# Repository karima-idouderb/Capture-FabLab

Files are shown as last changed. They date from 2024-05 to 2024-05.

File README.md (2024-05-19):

# Capture FabLab Project

## Authors
- [BELABDELLI Rizlène](https://github.com/Riizlene)
- [BOUGHERARA Hanane](https://github.com/hanane-bougherara)
- [IDOUDERB Karima](https://github.com/karima-idouderb)
- [OUERFILI Chaïma](https://github.com/Chaimaaaaaaaaaaa)

## Overview
The Capture FabLab project was designed to address a crucial need within the FabLab: project documentation. Often overlooked or considered tedious by users, the documentation process has been simplified through a system that captures videos of the work being done and automatically uploads them to a dedicated server. This project aims to make documentation more accessible and attractive, encouraging comprehensive and regular recording throughout a project's lifecycle. This will facilitate the continuation, improvement, reproduction, and collaboration on projects within the FabLab community.

## Table of Contents
1. [Introduction](#introduction)
2. [Client Requirements](#client-requirements)
3. [System Architecture](#system-architecture)
4. [Project Development Stages](#project-development-stages)
5. [Project Validation](#project-validation)
6. [Conclusion](#conclusion)

## Introduction
The Capture FabLab project was initiated to meet a critical need in the FabLab: project documentation. Users often neglect or find this step tedious. To streamline this process, we developed a system that captures videos of ongoing work and automatically sends them to a dedicated server. The primary goal is to make documentation more accessible and appealing, thereby encouraging users to document their projects comprehensively and consistently throughout their development. This initiative aims to facilitate the continuation, improvement, reproduction, and collaboration on projects within the FabLab.

## Client Requirements
- **Video Recording Control**: Ability to start and stop video recording on demand.
- **User-friendly Interface**: Simple interface with easily identifiable buttons for starting and stopping video recording, ensuring intuitive use.
- **Battery Power**: The system must be powered by a rechargeable battery with a minimum autonomy of 6 hours and a maximum recharge time of 8 hours.
- **Recording Indicator**: An LED should clearly indicate when video recording is in progress.
- **Framerate Adjustment**: A dial to adjust the video framerate, providing flexibility in recording quality.
- **Video Storage on Dedicated Server**: Set up a server to store captured videos, ensuring data preservation and availability for FabLab users.
- **Automatic Data Transfer**: Videos should be automatically transferred from the Raspberry Pi 4 (or other components) to the server upon recording, ensuring continuous documentation.
- **Ease of Assembly for Makers**: The system should be easy to assemble and reproduce, encouraging wider adoption within the FabLab community.
- **Portable and Practical Prototype**: The prototype should be compact and lightweight for easy relocation and use in different FabLab contexts.

## System Architecture
- **Raspberry Pi 4**: Acts as the system's brain, running Python code to control video capture, manage webcam settings, handle recording, and manage video transfers to the server.
- **Webcam**: Used to capture videos of FabLab projects, connected to the Raspberry Pi 4 and controlled by the Python code.
- **External Battery**: Provides continuous power for a minimum of 6 hours as required by the client.
- **PCB (Printed Circuit Board)**: Connects and organizes electronic components, ensuring a compact layout and stable connections.
- **Enclosure**: A specially designed box houses and protects all system components, robust enough for FabLab environments while being compact for easy transport.

## Project Development Stages
1. **Research and Integration of Video Recording Code**: We began by researching and testing Python codes to capture videos from a webcam and store them on the Raspberry Pi 4. Once a functional code was found, it was modified to integrate into the system, ensuring basic recording functionality.
2. **Integration of Control Buttons**: Physical buttons were added to the system to start and stop video recording. These buttons were connected to the Raspberry Pi 4 and programmed to trigger the appropriate actions in the Python code.
3. **Framerate Selection Using a Strip Switch**: A strip switch was used to allow users to select different predefined framerate values for the video, as the Raspberry Pi 4 can only handle numerical values for framerate. This approach was chosen over a potentiometer to avoid additional analog-to-digital conversion.
4. **Testing and Adjustments**: After integrating the main functionalities, tests were conducted to ensure everything worked correctly. Adjustments were made to the code and hardware based on test results to ensure system reliability.
5. **Enclosure Design**: During development, the enclosure design was finalized to house all components neatly.

## Project Validation
- **Regular Client Meetings**: Bi-weekly meetings with the client were held to discuss project progress, gather feedback on developed features, and obtain advice and recommendations. These meetings ensured transparent and effective communication, ensuring the project met the client's needs.
- **Regular Testing**: Continuous testing was performed throughout development to verify that all system functionalities worked correctly, including video recording, control buttons, framerate selection, etc.
- **Internal Team Meetings**: Regular team meetings were held to organize tasks, discuss challenges, and resolve any obstacles. These meetings ensured effective collaboration and smooth project progress.

## Conclusion
The Capture FabLab project has been successful on many fronts. Not only did we deliver a functional and reliable prototype on time, but we also gained valuable skills and experiences for future projects. Despite the challenges encountered, our determination and commitment were key to our success. This project represents an important milestone in our professional journey, and we are proud of the contribution we have made to the FabLab community.

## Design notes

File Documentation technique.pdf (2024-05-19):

BELABDELLI Rizlène
BOUGHERARA Hanane
IDOUDERB Karima
OUERFILI Chaïma

# Documentation Technique: Système d'Enregistrement Vidéo avec Raspberry Pi

## Sommaire

## Introduction

Ce document fournit des instructions détaillées pour la réalisation d'un système d'enregistrement vidéo à l'aide d'un Raspberry Pi. Le projet nécessite un ensemble spécifique de matériel ainsi que des étapes d'installation logicielle et de configuration.
Vous trouverez sur le lien github suivant le code nécessaire à la réalisation de ce projet ainsi que le fichier pour réaliser le PCB.
https://github.com/karima-idouderb/Capture-FabLab.git

## Matériel Requis

- Raspberry Pi 4
- Micro SD et Adaptateur
- Webcam USB
- 2 LEDs
- 2 Boutons
- Strip switch EECO
- PCB
- Jumpers femelle femelle
- Écran, clavier, souris et câble HDMI (+adaptateur Micro HDMI-HDMI) pour le coder sur la carte

## Étapes de Configuration

### 1. Installation du Système d'Exploitation sur la Carte SD

Utilisez Raspberry Pi Imager pour cette étape.

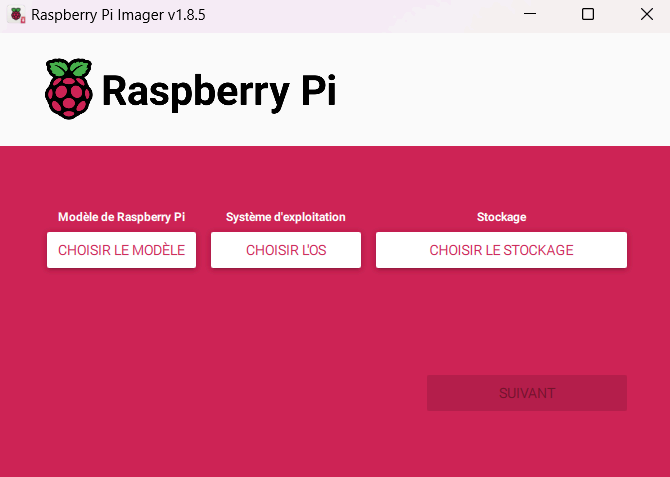
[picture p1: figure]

### 2. Démarrage du Raspberry Pi

Suivez simplement les instructions du programme de configuration initiale. Dans notre exemple, nous avons utilisé "abc" comme nom d'utilisateur et mot de passe. Assurez-vous de modifier le chemin d'enregistrement des vidéos si vous utilisez un nom d'utilisateur différent.

result = cv2.VideoWriter('/home/’NOM_UTILISATEUR’/Projet/Videos/' + nom_fichier + '.avi', cv2.VideoWriter_fourcc(*'MJPG'), fps, size)

### 3. Installation des Librairies Nécessaires

Utilisez les commandes suivantes pour installer les librairies requises:

- OpenCV (pour l'enregistrement vidéo à partir de la caméra):

sudo apt install python3-opencv

- LGPIO (pour gérer les GPIO de la Raspberry Pi):

sudo apt install python3-rpi-lgpio

### 4. Code pour l'Enregistrement Vidéo

Ajoutez le fichier "final.py" dans le répertoire suivant (créez-le si nécessaire):

/home/abc/Projet

Les vidéos seront enregistrées dans le répertoire suivant:

/home/abc/Projet/Videos

Pour lancer le programme au démarrage, ajoutez une ligne dans le fichier "rc.local". Utilisez la commande suivante pour modifier le fichier:

sudo nano /etc/rc.local

Ajoutez la ligne suivante avant "exit 0":

sudo python3 /home/abc/Projet/final.py &

Quelques commentaires sur le code :
La variable fps à la ligne 62 ne représente pas exactement le nombre de frames par seconde. Il y a un petit décalage probablement dû à l'exécution de la boucle. Cependant, la modification de cette valeur permet d'ajuster la vitesse de l'enregistrement. Une valeur de 5 sur la molette correspond à peu près à la vitesse réelle, 1 étant plus lent et 9 plus rapide.

### 5. Configuration du Serveur

Avec l'aide de monsieur Julien Vincent, nous avons mis en place un serveur web Apache accessible à l'adresse suivante : http://pc5033.polytech.upmc.fr/~pltuser/. Ce serveur est uniquement accessible depuis l'intérieur du réseau Polytech.
Afin de faciliter l'envoi de données sans avoir à entrer un mot de passe, nous avons généré une clé privée sur la Raspberry Pi 4. Cette clé est enregistrée du côté du serveur à l'aide de la commande suivante :

ssh-keygen -t n° de la clé publique (.pub) du serveur.

Pour comparer le contenu à envoyer avec ce qui est déjà présent sur le serveur, nous utilisons la commande rsync :
rsync -arv /home/abc/Projet/Videos/ pltuser@pc5033.polytech.upmc.fr:/home/pltuser/Videos Autrement dit, cela nous permettra de synchroniser les données.

Pour automatiser les commandes, nous avons édité le fichier crontab. Nous nous sommes aidés de Crontab Generator pour cette étape.

Pour supprimer toutes les deux semaines les vidéos de plus de 5 jours, nous avons ajouté la commande suivante au crontab :
0 0 */14 * * find /home/Projet/Videos/ -name '*.avi' -type f -mtime +5 -exec rm {} \;

L'envoi des données est automatisé en ajoutant la commande rsync évoquée précédemment au crontab.

Pour agir directement sur le serveur, par exemple pour supprimer des vidéos ou créer un nouveau dossier, nous utilisons la commande ssh :
ssh pltuser@pc5033.polytech.upmc.fr ls /home/pltuser/Videos/

Cela permet d'effectuer diverses opérations administratives sur le serveur.

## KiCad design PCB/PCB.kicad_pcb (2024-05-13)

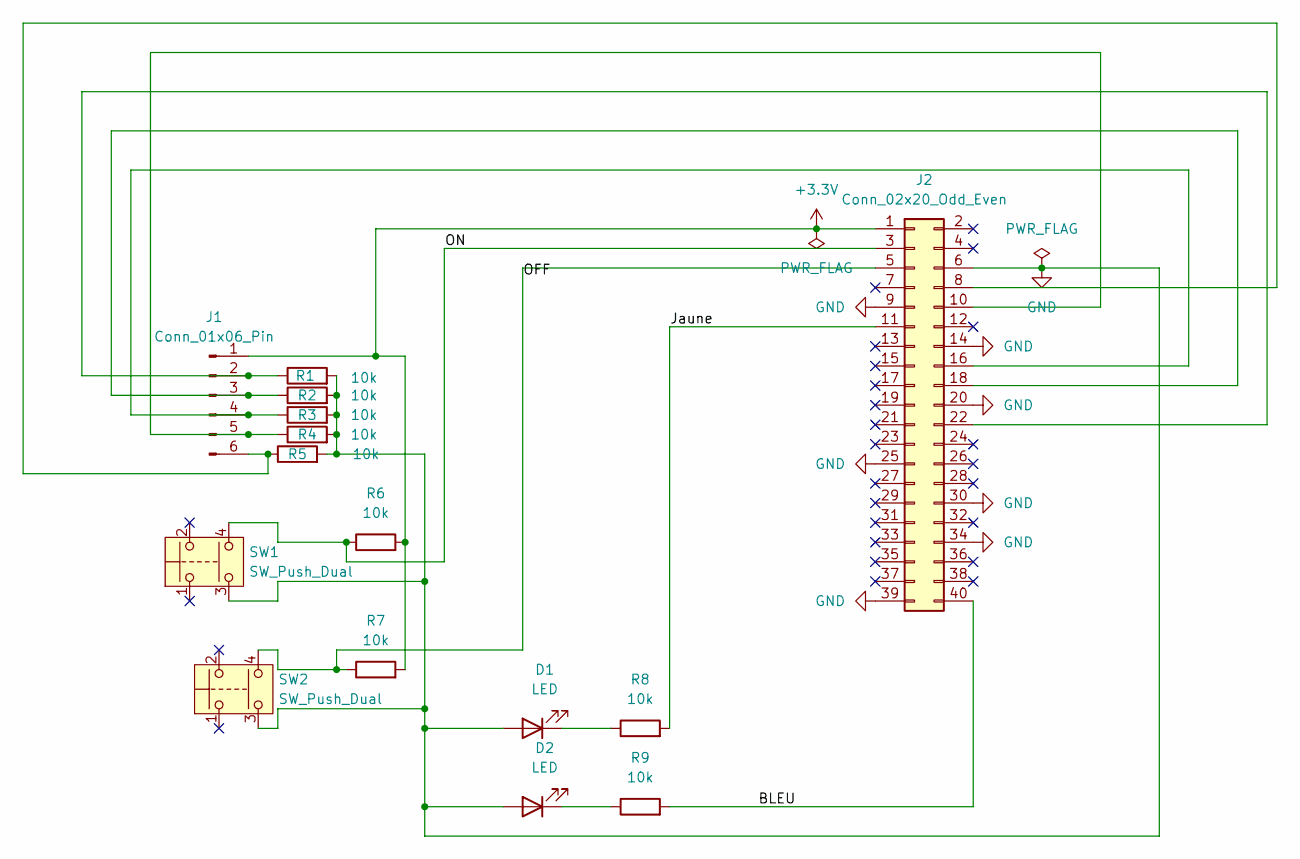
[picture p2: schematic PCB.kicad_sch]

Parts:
D1, D2: LED; LED_D5.0mm
J1: Conn_01x06_Pin; PinSocket_1x06_P2.54mm_Vertical
J2: Conn_02x20_Odd_Even; PinSocket_2x20_P2.54mm_Vertical
R1, R2, R3, R4, R5, R6, R7, R8, R9: 10k; R_Axial_DIN0207_L6.3mm_D2.5mm_P10.16mm_Horizontal
SW1, SW2: SW_Push_Dual; Push_E-Switch_KS01Q01

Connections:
+3.3V: J1.1, J2.1, R6.2, R7.2
/BLEU: J2.40, R9.2
/Jaune: J2.11, R8.2
/OFF: J2.5, R7.1, SW2.4
/ON: J2.3, R6.1, SW1.4
GND: D1.2 (A), D2.2 (A), J2.6, J2.9, J2.14, J2.20, J2.25, J2.30, J2.34, J2.39, R1.2, R2.2, R3.2, R4.2, R5.2, SW1.3, SW2.3
unnamed: D1.1 (K), R8.1
unnamed: D2.1 (K), R9.1
unnamed: J1.2, J2.22, R1.1
unnamed: J1.3, J2.18, R2.1
unnamed: J1.4, J2.16, R3.1
unnamed: J1.5, J2.10, R4.1
unnamed: J1.6, J2.8, R5.1

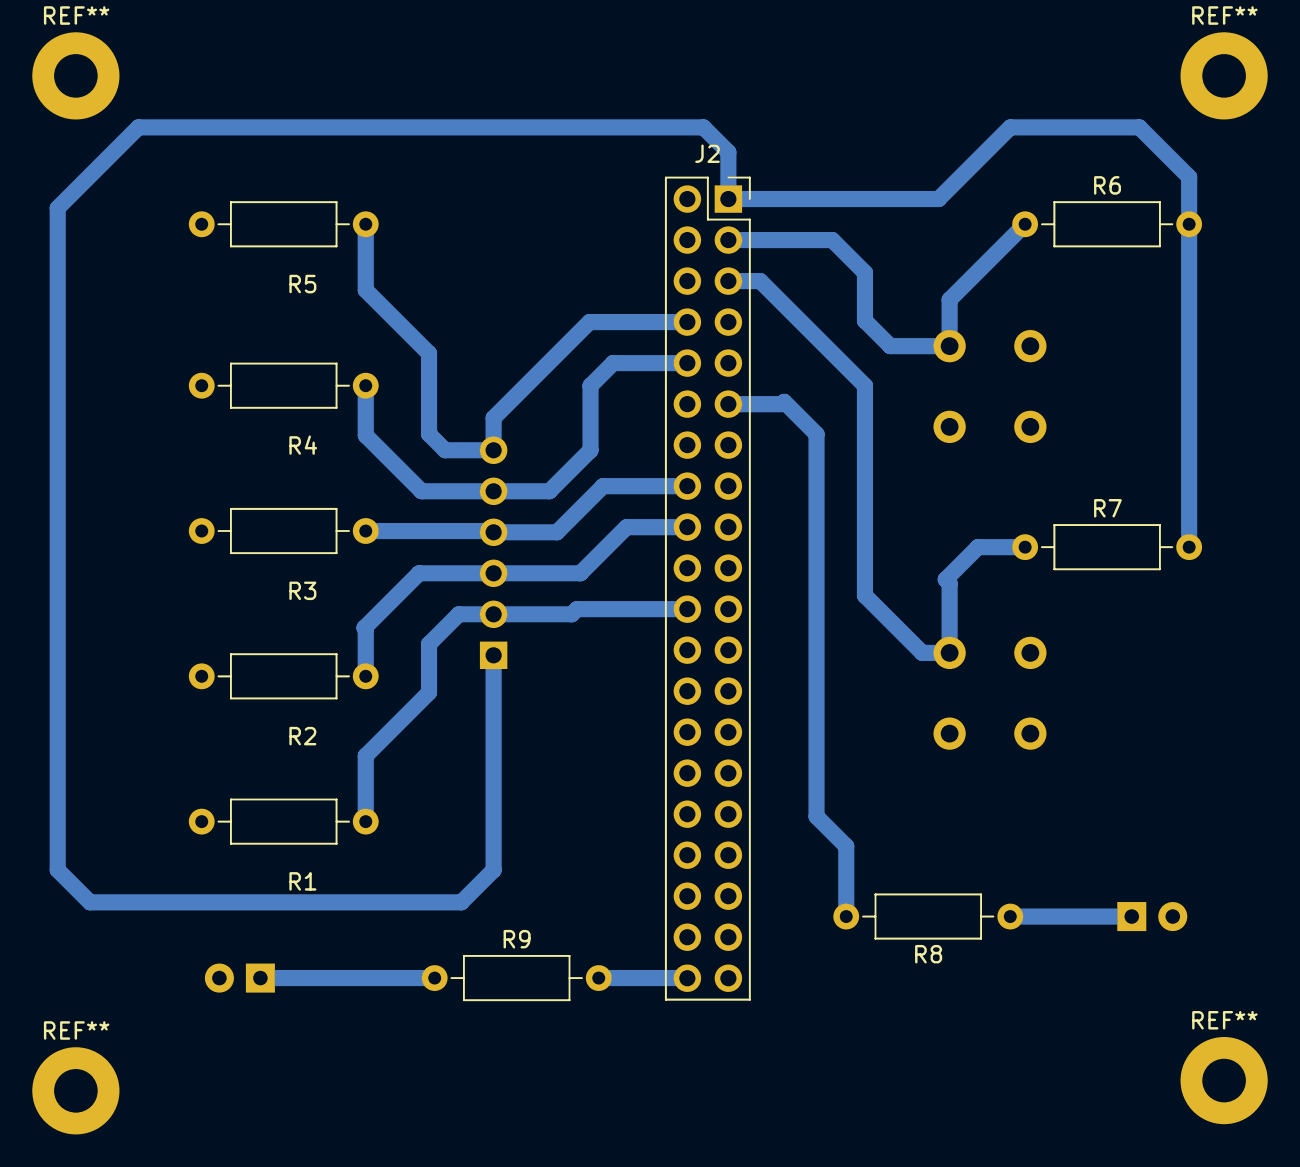
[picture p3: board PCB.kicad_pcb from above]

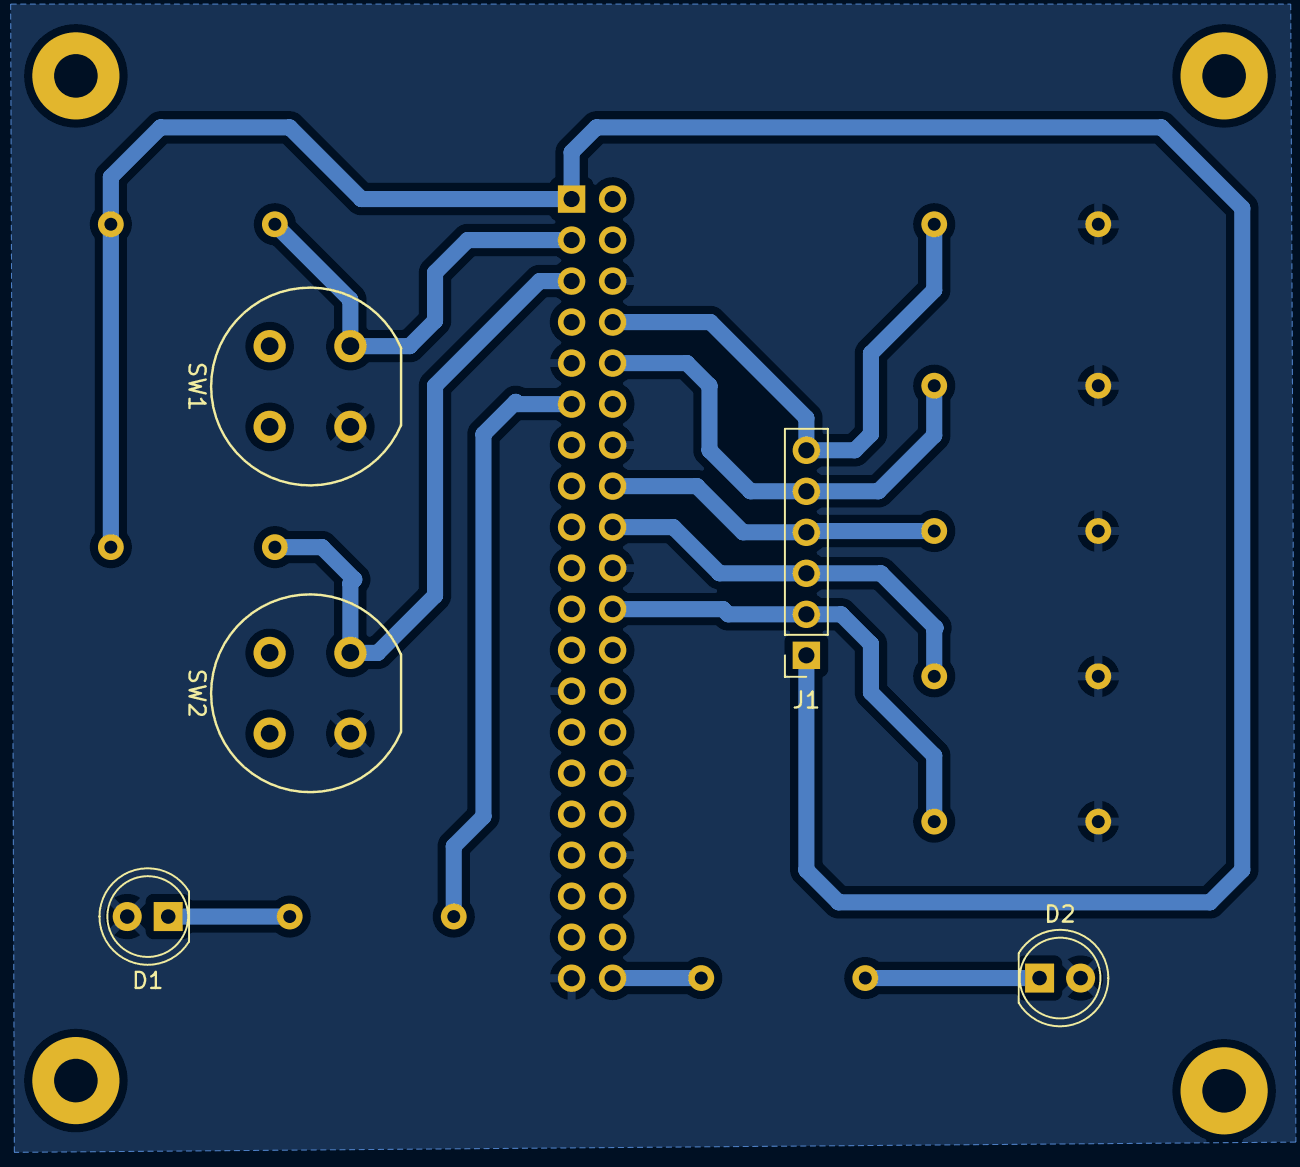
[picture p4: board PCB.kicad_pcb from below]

Board: 2 copper layers, 15 parts (5 on the bottom side), 13 nets.

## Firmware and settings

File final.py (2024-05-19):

# Enregistrement de vidéo avec boutons start/stop et molette pour changer le frame rate                                                                                                                                                                                                                                                                                                                                
import cv2
from gpiozero import Button, LED
from datetime import datetime
from time import sleep
import lgpio

# Pins de la molette
GPIO = lgpio.gpiochip_open(0)
lgpio.gpio_claim_output(GPIO, 17) # LED de démarrage
lgpio.gpio_claim_output(GPIO, 21) # LED d'enregistrement

# Boutons
button_on = Button(3)
button_off = Button(2,bounce_time=0.2)

# Pour sortir de la boucle d'enregistrement
stop_enrg = True

# Interruption pour le bouton stop
def init():
    button_off.when_pressed = OFF

# Fonction appelée par l'interruption, met la variable stop_enrg à false pour sortir de la boucle d'enregistrement
def OFF():
    global stop_enrg
    stop_enrg = False
    for _ in range(3):
        lgpio.gpio_write(GPIO, 17, 1)
        sleep(0.2)
        lgpio.gpio_write(GPIO, 17, 0)
        sleep(0.2)
    lgpio.gpio_write(GPIO, 21, 0)

# Retourne la valeur choisie par la molette + 1
def molette():
    valeur_inv = [lgpio.gpio_read(GPIO, pin) for pin in [14, 15, 23, 24, 25]]
    valeur = [0 if inv else 1 for inv in valeur_inv]
    valeur_ = valeur[0] * 1 + valeur[1] * 2 + valeur[2] * 4 + valeur[3] * 8 + valeur[4] * 8 + 1
    return valeur_

def main():
    global stop_enrg
    while True:
        if button_on.is_pressed:
            stop_enrg = True
            # Lancement de l'enregistrement après 3 clignotements
            for _ in range(3):
                lgpio.gpio_write(GPIO, 17, 1)
                sleep(0.2)
                lgpio.gpio_write(GPIO, 17, 0)
                sleep(0.2)
            lgpio.gpio_write(GPIO, 21, 1)
            nom_fichier = datetime.now().strftime("%Y-%m-%d %H:%M:%S")
            video = cv2.VideoCapture(0)
            if not video.isOpened():
                print("Erreur de lecture du fichier")
                return
            frame_width = int(video.get(3))
            frame_height = int(video.get(4))
            size = (frame_width, frame_height)
            fps = molette()
            print("______________________frame", fps)
            # Modifier le chemin d'enregistrement des vidéos si necessaire
            result = cv2.VideoWriter('/home/abc/Projet/Videos/' + nom_fichier + '.avi', cv2.VideoWriter_fourcc(*'MJPG'), fps, size)
            while stop_enrg:
                print("enrg")
                ret, frame = video.read()
                if ret:
                    result.write(frame)
                else:
                    break
            # Relâcher tout à la fin
            video.release()
            result.release()
            print("Vidéo enregistrée\n")

if __name__ == "__main__":
    # Clignote 2 fois pour indiquer que le programme est lancé
    for _ in range(2):
        lgpio.gpio_write(GPIO, 17, 1)
        sleep(0.1)
        lgpio.gpio_write(GPIO, 17, 0)
        sleep(0.1)
    init()
    main()
